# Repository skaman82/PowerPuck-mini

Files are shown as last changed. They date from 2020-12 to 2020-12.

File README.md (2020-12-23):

# PowerPuck-mini
2S Li-Ion power system for FPV goggles (allows the use of full capacity potential of li-ion cells). This is the second version whitch is much easier to build compaired to V1 (and is also much smaller).

# Features:
• 9V Step-Up from a 2S source <br>
• On/off button<br>
• Adjustable low-voltage alarm<br>
• LED power and capacity indicator<br>

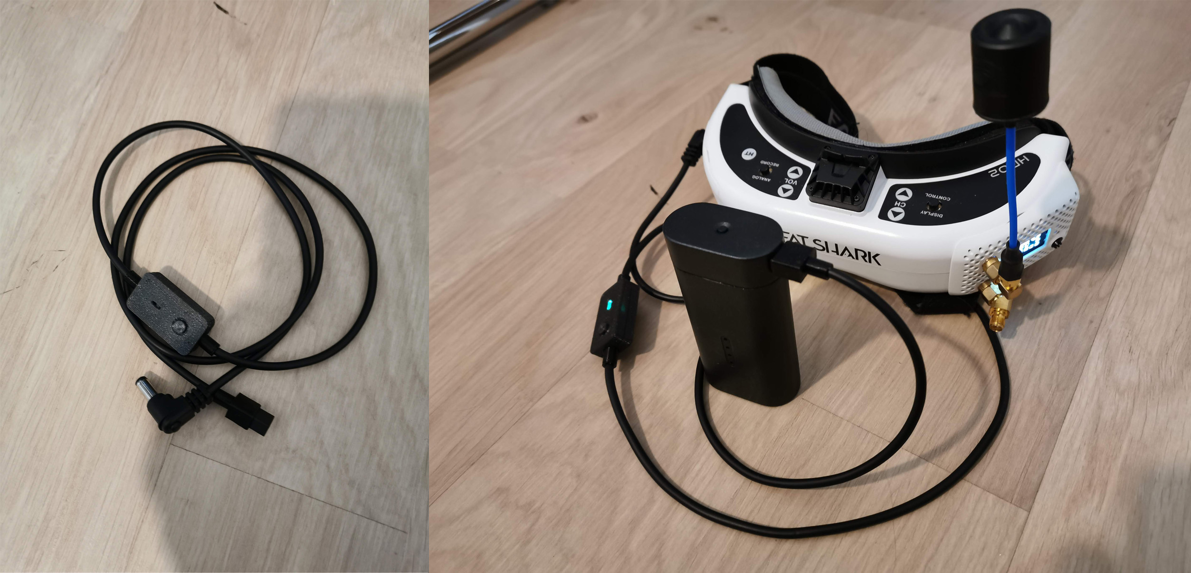
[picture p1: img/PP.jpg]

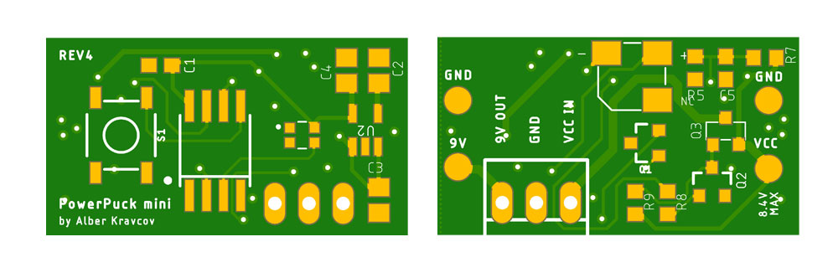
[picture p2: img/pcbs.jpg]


# PARTS:
Notes: Voltage divider is currently designed for 10v max. <br>

## PCB
C1,C5: 		100nF C0603 Capacitor (2x)<br>
C2: 		10nF C0805 Capacitor (1x)<br>
C3: 		1uF C0805 Capacitor 25V (1x)<br>
C4: 		2.2uF C0805 Capacitor (1x)<br>
LS1: 		Speaker CSS-0575B-SMT (1x)<br>
Q1, Q2:		BC848 30V 100mA SOT23-3 Transistor (2x)<br>
Q3: 		IRLML6402 Power Mosfet (1x)<br>
R8, R9:	  5k6 R0603 Resistor (2x)<br>
R7, R5: 		10k R0603 Resistor (2x)<br>
S1: 		MOMENTARY-SWITCH SMD 5.2MM (1x)<br>
U1: 		WS2812-2020 LED (1x)<br>
U2: 		LP2985 5V LDO Reg (1x)<br>
•: 		ATTINY85 SOIC8 (1x)<br><br>

## Additional
+ Produced PCB (0.8-1mm thicknes required for the case)<br>
+ U3V12F9		Pololu 9V Step-Up<br>
+ Printed case parts (use PETG because of the heat from the step-up. TPU for the relief)<br>
+ ISP flashing tool (and SOIC8 clamp) like USBTinyISP<br>
+ 1.5m 5.5 x 2.1 DC cable like this: https://www.ebay.de/itm/0-50-1-00-1-50-m-USB-DC-Kabel-5-5-x-2-1-2-5-mm-Winkelstecker-CU-15855/293148509182 (cut the USB and replace it with your own connector)<br>
+ 2S li-ion battery pack. 3500mah 18650 will last about 3.5h, 5000mah 21700 will last about 5h. 18650 DIY battery case see the V1: https://github.com/skaman82/PowerPuck<br>

# ASSEMBLY
+ Solder all the SMD parts and the step-up to the PCB
+ Compile and flash the code with ArduinoIDE using an ISP programmer (use the right hardware package mentioned in the code)
+ Connect to a 2S power source and test if everything is working
+ Solder on the cables, put it in the pinted case and glue it together

# OPERATION
Connect the battery. The device is powered on and the LED is showing the battery status as follows: <br>
+ GREEN: voltage is 4.20 - 3.65v per cell (full)<br>
+ YELLOW: voltage is 3.64- 3.45v per cell (half)<br>
+ RED: voltage is 3.44 - alarmvoltage (one third)<br>
+ BLINKING RED and beeping: voltage is below alarm voltage<br>
<br>
- Press the button once to toggle between ON and OFF state.<br>
- Press the button for 2 sek. to enter the setup-menu<br>
<br>
SETUP MENU:<br>
Press the button to toggle between settings:<br>

• GREEN: voltage alarm at 3.35v per cell<br>
• YELLOW: voltage alarm at 3.25v per cell<br>
• RED: voltage alarm at at 3.15v per cell<br>
- Press the button for 2 sek. to save your alarm setting and exit the setup menu <br>

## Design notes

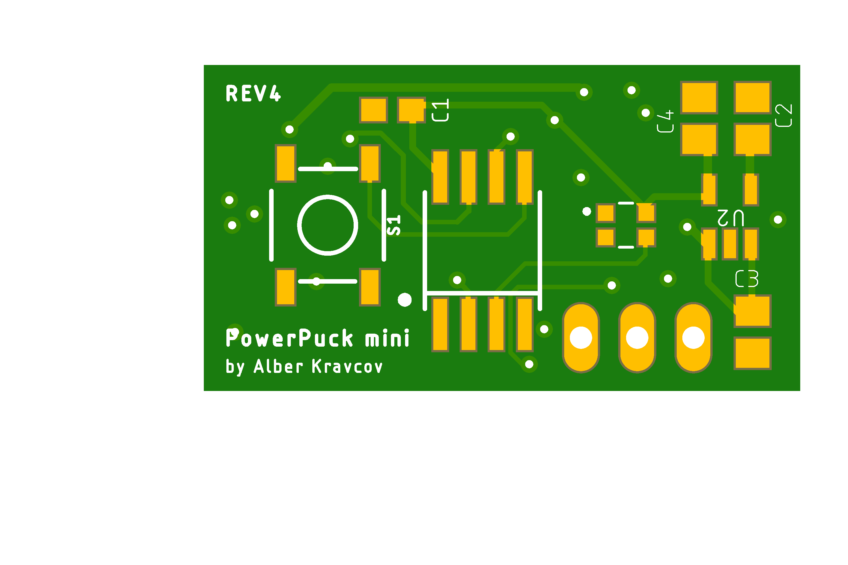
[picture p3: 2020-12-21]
PCB files/powerpuck_mini v4_t.png

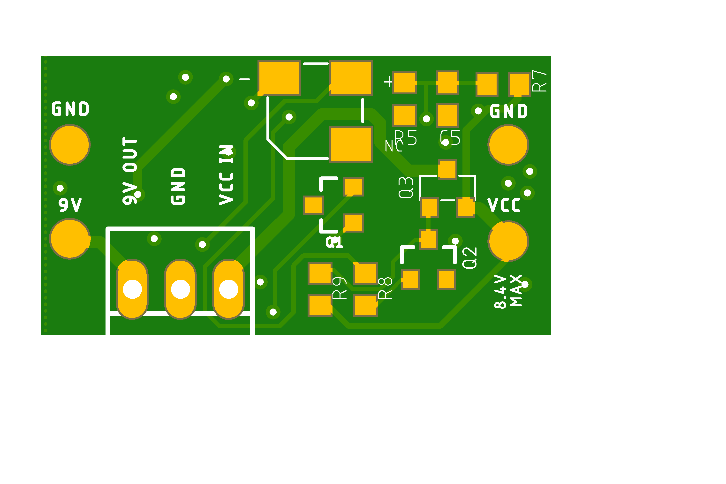
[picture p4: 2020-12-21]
PCB files/powerpuck_mini v4_b.png

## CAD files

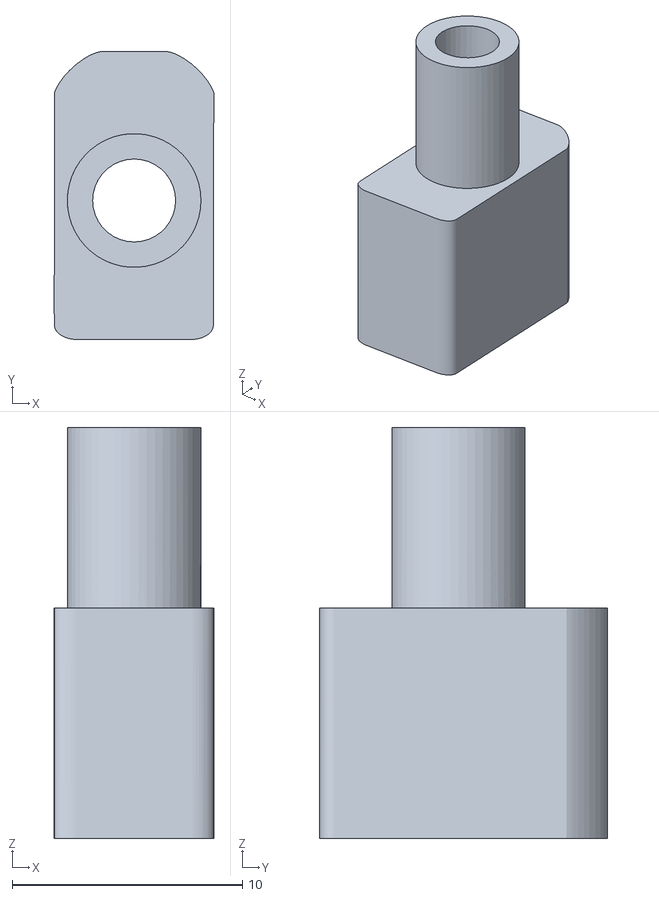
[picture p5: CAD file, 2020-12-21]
Case files/xt30_relief.stl
6.93 x 12.5 x 17.8

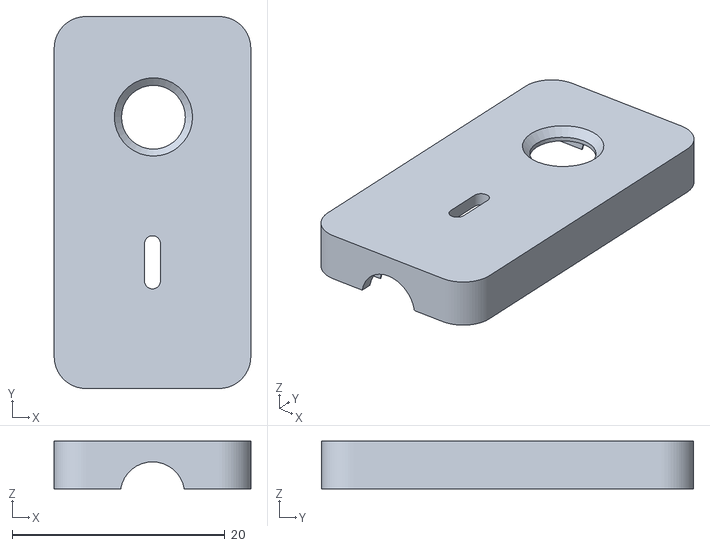
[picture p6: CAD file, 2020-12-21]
Case files/case_top_fixed.stl
18.5 x 35.0 x 4.50

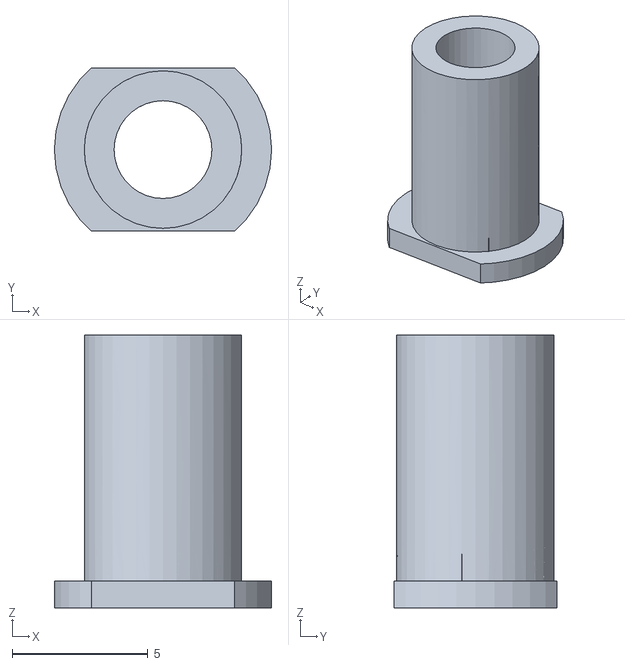
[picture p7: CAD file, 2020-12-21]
Case files/case_cable_relief_fixed.stl
8.00 x 6.01 x 10.1

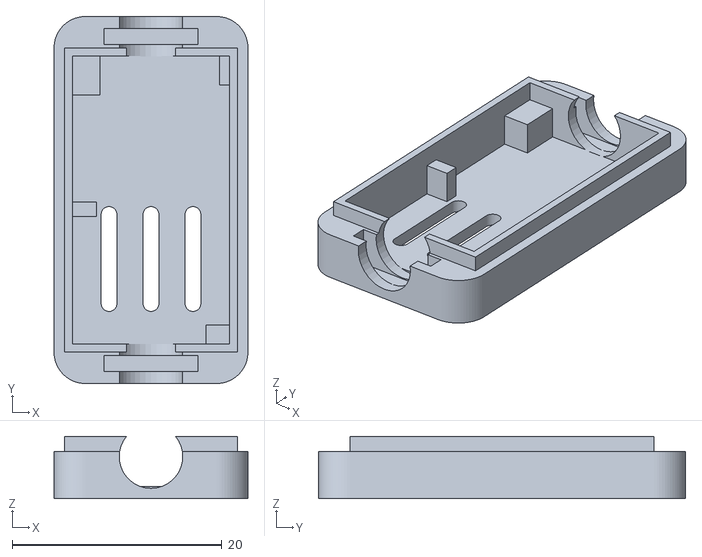
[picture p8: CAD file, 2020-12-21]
Case files/case_bottom_fixed.stl
18.5 x 35.0 x 5.95

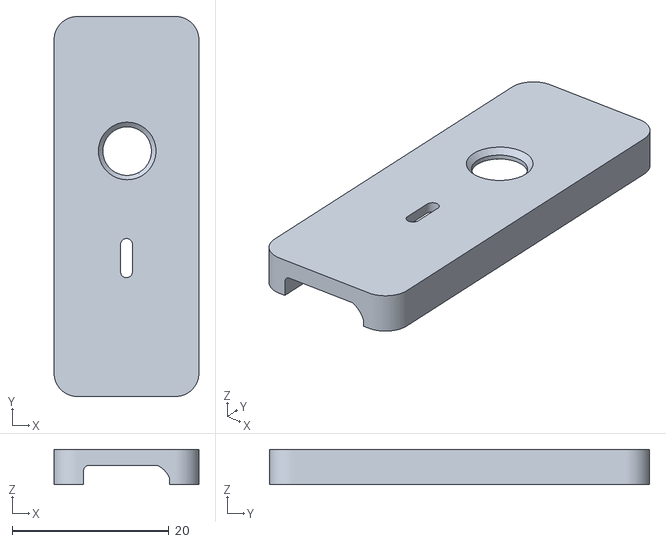
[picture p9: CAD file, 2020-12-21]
Case files/caseXT30_top_fixed.stl
18.5 x 48.5 x 4.50

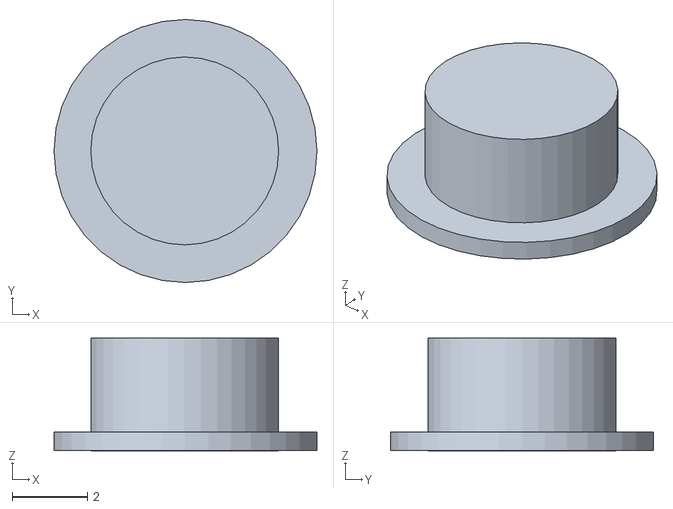
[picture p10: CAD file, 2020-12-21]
Case files/case_button_fixed.stl
7.00 x 7.00 x 3.00

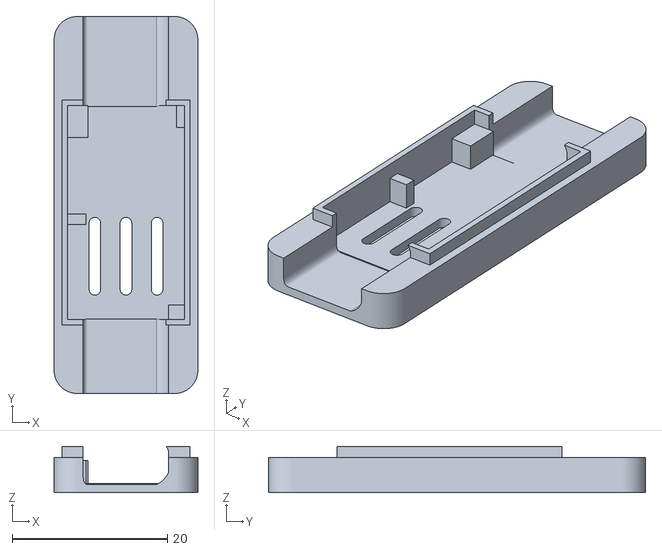
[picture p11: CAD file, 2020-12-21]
Case files/caseXT30_bottom_fixed.stl
18.5 x 48.5 x 5.95

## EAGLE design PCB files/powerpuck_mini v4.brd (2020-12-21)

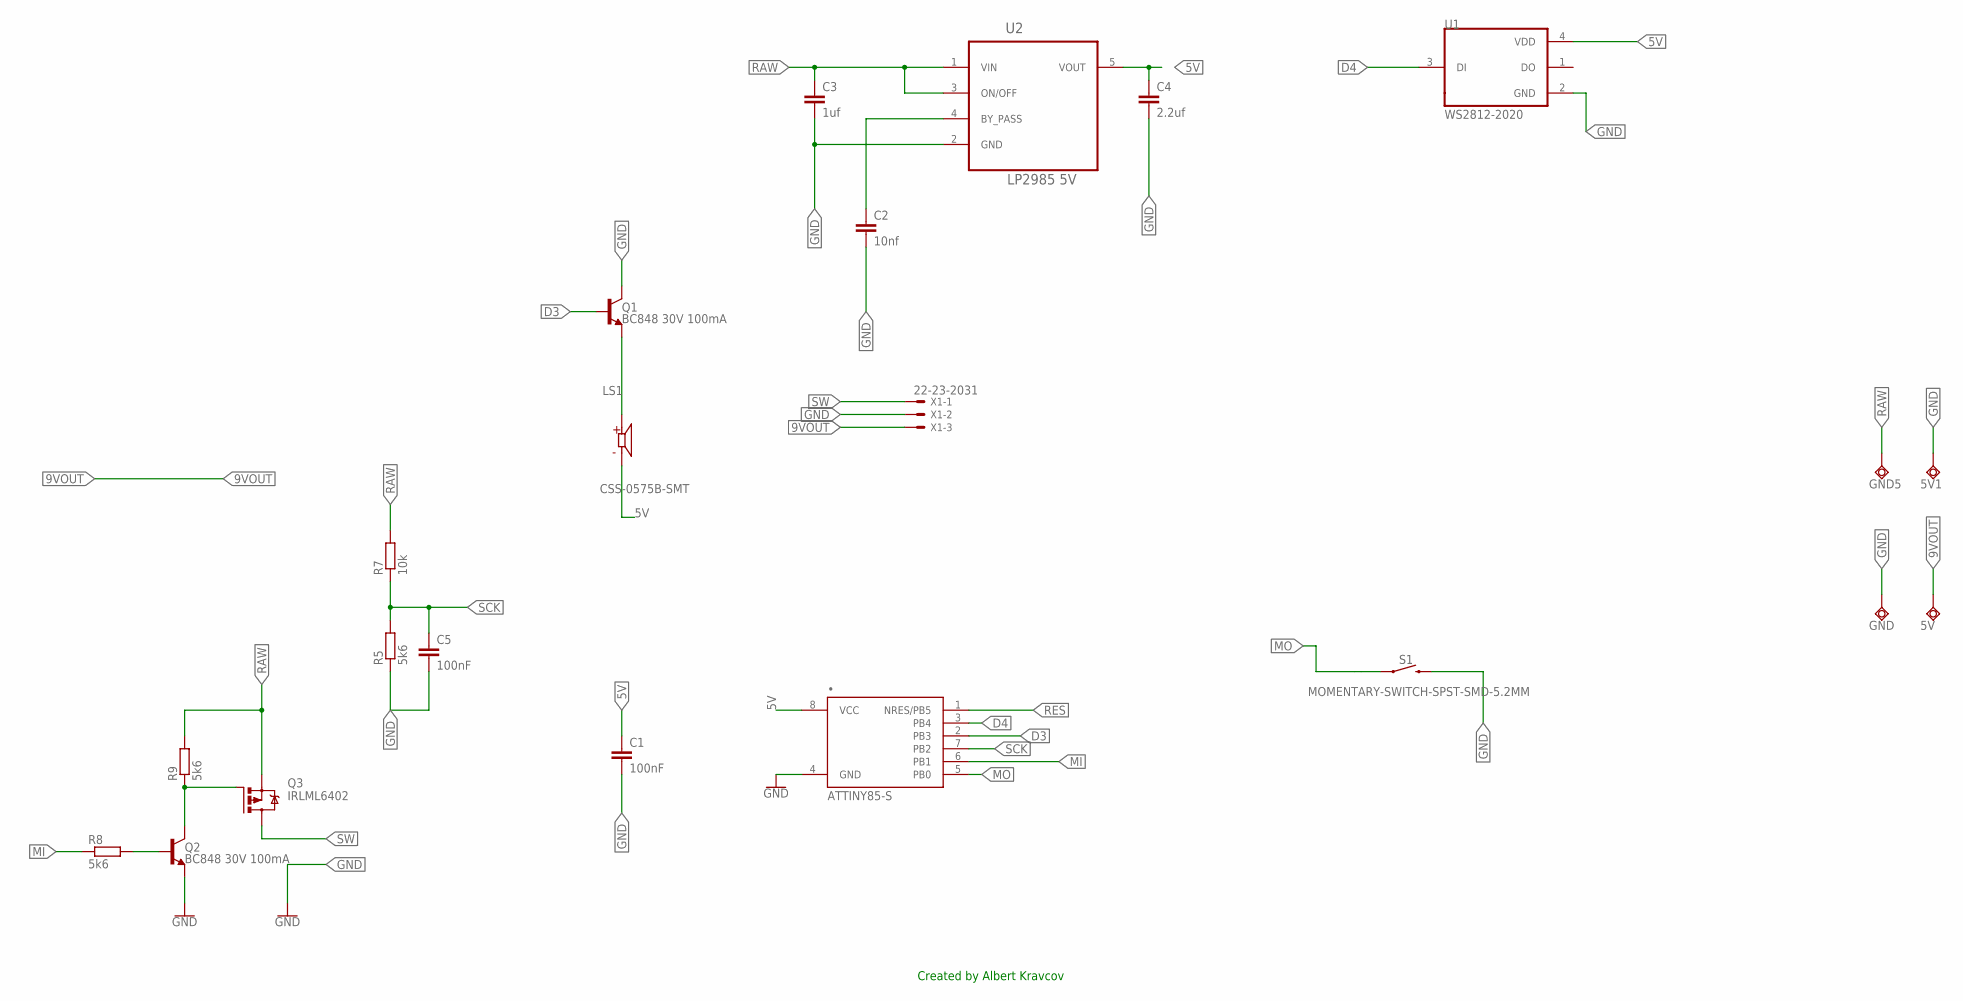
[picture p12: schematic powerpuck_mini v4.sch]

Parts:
5V, 5V1: TPSQTP20R; TP20R
C1, C5: 100nF; C0603
C2: 10nf; C0805
C3: 1uf; C0805
C4: 2.2uf; C0805
GND, GND5: TPSQTP20R; TP20R
LS1: CSS-0575B-SMT; CUI_CSS-0575B-SMT
Q1, Q2: BC848 30V 100mA; SOT23-3
Q3: IRLML6402; MICRO3
R5, R8, R9: 5k6; R0603
R7: 10k; R0603
S1: MOMENTARY-SWITCH-SPST-SMD-5.2MM; TACTILE_SWITCH_SMD_5.2MM
U1: WS2812-2020; LED_WS2812-2020
U2: LP2985 5V; SOT95P284X119-5N
X1: 22-23-2031
•: ATTINY85-S; SOIC8_EIAJ_208MIL

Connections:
5V: C1.1, C4.1, LS1.2 (N), U1.4 (VDD), U2.5 (VOUT), •.8 (VCC)
9VOUT: 5V.TP, X1.3
D3: Q1.1 (B), •.2 (PB3)
D4: U1.3 (DI), •.3 (PB4)
GND: 5V1.TP, C1.2, C2.2, C3.2, C4.2, C5.2, GND.TP, Q1.3 (C), Q2.2 (E), R5.1, S1.3 (2), U1.2 (GND), U2.2 (GND), X1.2, •.4 (GND)
MI: R8.1, •.6 (PB1)
MO: S1.1, •.5 (PB0)
unnamed: C2.1, U2.4 (BY_PASS)
unnamed: LS1.1, Q1.2 (E)
unnamed: Q2.1 (B), R8.2
unnamed: Q2.3 (C), Q3.1 (G), R9.1
RAW: C3.1, GND5.TP, Q3.2 (S), R7.2, R9.2, U2.1 (VIN), U2.3 (ON/OFF)
RES: •.1 (NRES/PB5)
SCK: C5.1, R5.2, R7.1, •.7 (PB2)
SW: Q3.3 (D), X1.1

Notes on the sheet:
Created by Albert Kravcov

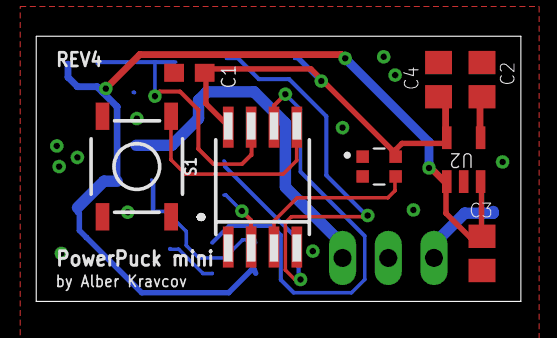
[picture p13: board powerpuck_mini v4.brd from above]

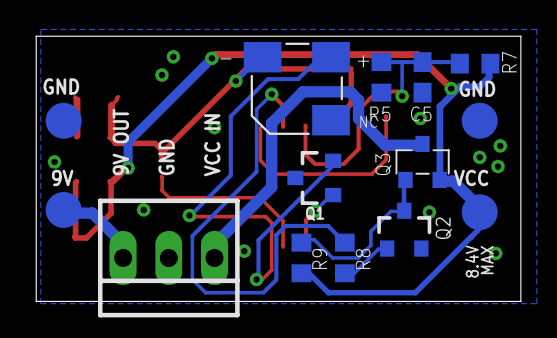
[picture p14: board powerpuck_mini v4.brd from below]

Board: 2 copper layers, 26.9 x 14.7 mm, 22 parts (14 on the bottom side), 14 nets.

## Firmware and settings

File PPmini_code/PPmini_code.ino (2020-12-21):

// ATtinyCore AT85 (https://github.com/SpenceKonde/ATTinyCore)
// millis and tone, 8mhz
// upload through USBTinyISP


#define voltage_scale   4.975   // play with this number to adjust voltage scale
#define R1              10000   // Voltage Divider Resistor1 10k
#define R2              10000   // Voltage Divider Resistor2 10k

#define BZ_pin          3       // Buzzer
#define GATE_pin        1       // Mosfet
#define VBAT_pin        A1      // vsens pin
#define BT_pin          0       // Button
#define LED_pin         4       // LED
#define longpresstime   1000    // in ms
#define alarmADDR       1       // EEPROM Adress

#include <EEPROM.h>
#include <Adafruit_NeoPixel.h>
Adafruit_NeoPixel pixels = Adafruit_NeoPixel(1, LED_pin, NEO_GRB + NEO_KHZ800);

byte pressedbut = 0;
byte i_butt = 0;
float voltage;
float cellvoltage;
byte celldetect = 0;
long previousMillis = 0;
long buzzermillis = 0;
byte alarmstate = 0; //lst
int vsens;
byte onstate = 1; //lst
int timer = 0;
int32_t alarmvalueEEP;
float alarmvoltage;
int menuselect;

void setup() {
  //pinMode(BZ_pin, OUTPUT);        //Buzzer
  pinMode(GATE_pin, OUTPUT);      //Mosfet Gate
  pinMode(VBAT_pin, INPUT);       //Voltage Input
  pinMode(BT_pin, INPUT_PULLUP);  //Button
  //pinMode(LED_pin, OUTPUT);       //Status LED

  pixels.begin(); // This initializes the NeoPixel library.
  pixels.clear();

  alarmvalueEEP = EEPROM.read(alarmADDR);

  if (alarmvalueEEP == 1)
  {
    alarmvoltage = 3.35;
  }
  else if (alarmvalueEEP == 2)
  {
    alarmvoltage = 3.25;
  }
  else if (alarmvalueEEP == 3)
  {
    alarmvoltage = 3.15;
  }
  else { }


digitalWrite(GATE_pin, HIGH);

}


byte buttoncheck()
{
  int i_butt = 0;
  byte buttonz = 0;
  if (digitalRead(BT_pin) != 1) {
    while (digitalRead(BT_pin) != 1)
    {
      delay(2);
      i_butt++;
    }
    buttonz = 1; //Button pressed

    if (i_butt > (longpresstime / 2))
    {
      buttonz += 1; //Button pressed long
      delay(2);
    }

  }


  pressedbut = buttonz;
  return buttonz;
}




void loop(void) {

  if (menuselect != 1) {

    buttoncheck();
    ReadVoltage();




    if (celldetect == 0) {

      //do something while voltage is not there yet
      tone(BZ_pin, 1000, 600); //beep for 500ms
    }

    else {

      if (cellvoltage < alarmvoltage) {
        unsigned long buzzertime = millis();
        if (buzzertime - buzzermillis > 1000) { // one second loop
          buzzermillis = buzzertime;

          if (alarmstate == 0) {
            alarmstate = 1;
            tone(BZ_pin, 500, 200); //beep for 200ms
            pixels.setPixelColor(0, 255, 0, 0); // red
            pixels.show();

          }
          else {
            alarmstate = 0;
            noTone(BZ_pin); //no beep
            pixels.setPixelColor(0, 0, 0, 0); // off
            pixels.show();
          }
        }
        else { }
      }


      if (pressedbut == 1) {

        if (onstate == 0) {
          onstate = 1;
          tone(BZ_pin, 100, 200); //beep for 100ms
          delay(200);
          tone(BZ_pin, 400, 150); //beep for 400ms
          //digitalWrite(LED_pin, HIGH);
          digitalWrite(GATE_pin, HIGH);

        }
        else {
          onstate = 0;
          tone(BZ_pin, 400, 200); //beep for 400ms
          delay(200);
          tone(BZ_pin, 100, 150); //beep for 100ms
          //digitalWrite(LED_pin, LOW);
          digitalWrite(GATE_pin, LOW);
        }
      }

      if (pressedbut == 2)
      {
        menuselect = 1;
        menu();
      }
      else { }

      updateLED();
    }

  }
  else {  }

}

void ReadVoltage(void) {

  vsens = analogRead(VBAT_pin);

  unsigned long updatetime = millis();

  if (updatetime - previousMillis > 1500) { // update voltage reading after some time
    previousMillis = updatetime;

    voltage = vsens * (voltage_scale / 1023.0) * ((R1 + R2) / R2); // Convert the analog reading (which goes from 0 - 1023) to a voltage, considering the voltage divider:

    if (celldetect == 0) {
      //detect cell count (dont really needed as the hardware is ment to be a 2S pack only)

      if (voltage > 17.1) {
        celldetect = 5;
      }
      else if ((voltage <= 17.1) && (voltage > 12.8)) {
        celldetect = 4;
      }
      else if ((voltage <= 12.8) && (voltage > 8.8)) {
        celldetect = 3;
      }
      else if ((voltage <= 8.8) && (voltage > 5.5)) {
        celldetect = 2;
      }
      else {
        celldetect = 1;
      }
    }

    cellvoltage = voltage / celldetect;

  }


}


void updateLED(void) {

  if (onstate == 1) {

    if (cellvoltage >= 3.65) {
      pixels.setPixelColor(0, 0, 150, 0); // green
      pixels.show();
    }
    else if ((cellvoltage < 3.65) && (cellvoltage >= 3.45)) {
      pixels.setPixelColor(0, 150, 69, 0); // yellow
      pixels.show();
    }
    else if ((cellvoltage < 3.45) && (cellvoltage >= alarmvoltage)) {
      pixels.setPixelColor(0, 150, 0, 0); // red
      pixels.show();
    }
    else if (cellvoltage < alarmvoltage) {
      //blinking red

      if (timer <= 2000) {
        // pixels.setPixelColor(0, 255, 0, 0); // blue just for testing
        // pixels.show();
        timer++;

        if ((timer <= 1000) && (timer < 2000)) {
          //  pixels.setPixelColor(0, 0, 0, 0); // off
          //  pixels.show();
        }

        if (timer == 2000) {
          timer = 0;
        }

      }

    }

  }

  else {
    pixels.setPixelColor(0, 0, 0, 0); // off
    pixels.show();
  }
}







void menu() {
  while (menuselect == 1) {
    buttoncheck();

    if (pressedbut == 2) {
      
      EEPROM.write(alarmADDR, alarmvalueEEP);
      tone(BZ_pin, 1000, 600); //beep for 500ms
      pixels.clear();
      menuselect = 0;
      return;
    }


    if (alarmvalueEEP == 1) { // green 3.35
      
      if (pressedbut == 1) {
        alarmvoltage = 3.25;
        alarmvalueEEP = 2;
      }

      //led color here
      pixels.setPixelColor(0, 0, 255, 0); // ^ green
      pixels.show();

    }
    else if (alarmvalueEEP == 2) { //yellow 3.25
      if (pressedbut == 1) {
        alarmvoltage = 3.15;
        alarmvalueEEP = 3;
      }
      //led color here
      pixels.setPixelColor(0, 200, 100, 0); // ^ yellow
      pixels.show();
      
      
      
    }

    else if (alarmvalueEEP == 3) { //red 3.15
      if (pressedbut == 1) {
        alarmvoltage = 3.35;
        alarmvalueEEP = 1;
      }
      //led color here
      pixels.setPixelColor(0, 255, 0, 0); // ^ white
      pixels.show();
     
    }

    else { 
pixels.setPixelColor(0, 250, 250, 250); // ^ white for error
      pixels.show();
      delay(1000);
      alarmvalueEEP = 1;
      }

  }

}

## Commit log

2020-12-21 initial upload
    [caseXT30_bottom_fixed.stl, caseXT30_top_fixed.stl, case_bottom_fixed.stl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]
2020-12-21 adding PCB images

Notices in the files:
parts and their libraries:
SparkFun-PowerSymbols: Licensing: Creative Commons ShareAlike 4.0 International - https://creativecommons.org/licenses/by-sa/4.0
